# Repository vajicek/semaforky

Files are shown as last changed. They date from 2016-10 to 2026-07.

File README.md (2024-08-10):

# semaforky
Android/Arduino-based DIY system for remote-controlled signaling for sport events

**NEW!: The next-gen version is based on a web app hosted by the device on its own Wi-Fi network. See [web_app](web_app).**

Semaforky is a client-server software for Android/web browsers and several Arduino-based controllers (clients) of various signaling devices:
- Semaphore lights (red, yellow, green)
- Segment clock display
- Siren/acoustic device

This platform was originally designed for archery competitions according to World Archery rules (see [rules](https://www.worldarchery.sport/rulebook/search/clock)). The solution is intended to replace an outdated cable-based predecessor.

## Original motivation

Server app             |  Client hardware
:-:|:-:
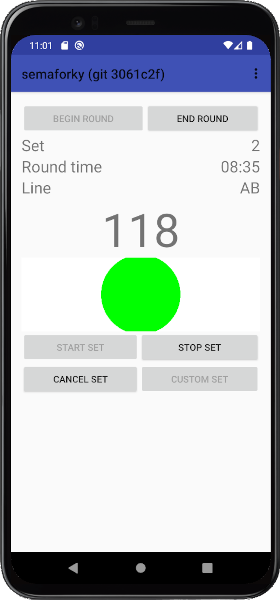
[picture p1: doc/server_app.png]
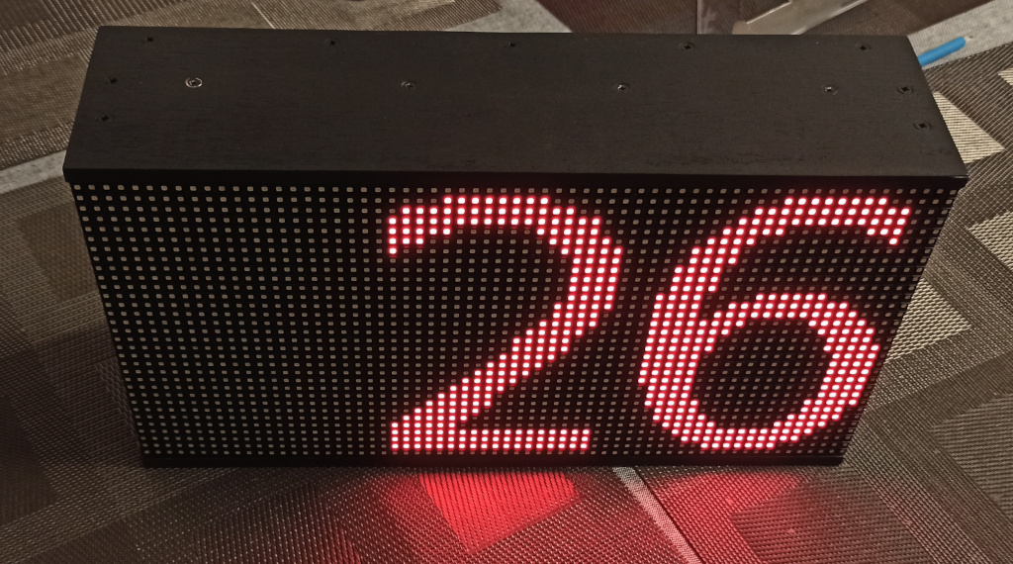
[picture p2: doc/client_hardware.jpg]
  |  

## Original goals
- Most of the existing devices should be preserved, with the addition of a remote transmitter and power source.
- Simple construction blueprints for hardware should also be provided (TBD).
- A simple [application](android_app) for Android, compatible with most existing devices, should be created to replace the Windows-based custom software.

## Second generation goals
- Provide new, original hardware that is battery-powered (via off-the-shelf power banks), mobile, and simple.
- See [blueprints](hardware).

## Third generation goals
- Replace the Android app with a device-hosted [web app](web_app) that runs on anything with a web browser (laptop, Android device, iPhone).

## Additional features
- Training mode: Various countdown and signaling scenarios (e.g., mini-games) for training coordination and timing for improved form in sports activities.

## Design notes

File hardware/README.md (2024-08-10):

# Hardware for semaforky

It provides plans for:
* PCBs
* Enclosures

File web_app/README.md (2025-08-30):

# semaforky webui
Android/Arduino-based hardware controlled via SPA (single page application) web app from any web browser (smartphone, tablet, laptop, PC, Mac, Windows, Linux, ...).

## Motivation

Any Web Browser          |  Hardware running REST/WEB server
:-:|:-:
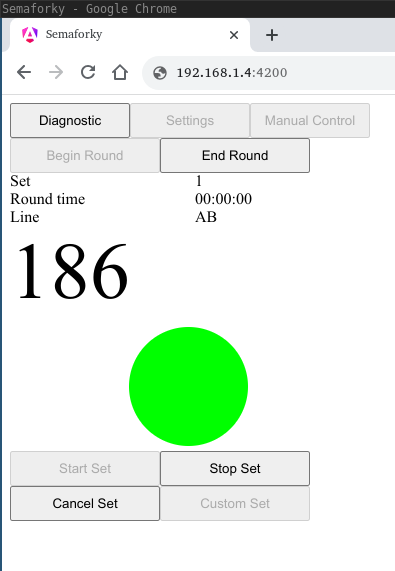
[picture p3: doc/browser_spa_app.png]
  |  

## Documentation

[User Guide](UserGuide_cz.md) (in czech)

## Live demo

See [Live demo](http://vajicek.github.io/semaforky).

## Prerequisites

* Arduino 1.8.19
* ESP 8266 board support for Arduino >=1.6.x, set "http://arduino.esp8266.com/stable/package_esp8266com_index.json" in File > Preferences > Additional Board Manger URLs
* [Support for SPIFFS](https://www.instructables.com/Using-ESP8266-SPIFFS/), [plugin v0.5](https://github.com/esp8266/arduino-esp8266fs-plugin/releases/download/0.5.0/ESP8266FS-0.5.0.zip)
* Arduino Libraries (Tools > Manage Libraries...)
    * [ESPAsyncTCP](https://github.com/me-no-dev/ESPAsyncTCP)
    * [ESPAsyncWebServer](https://github.com/me-no-dev/ESPAsyncWebServer)
    * [ArduinoJson](https://github.com/bblanchon/ArduinoJson)
    * DMD2
    * Adafruit GFX Library
    * Fork of [PxMatrix](https://github.com/vajicek/PxMatrix.git) (new scan pattern added)

## Use devcontainer

Build dev container.
```bash
make build_devcontainer
```

Run dev container.
```bash
make devcontainer
```

### Web application
Build **web app**.
```bash
make setup_ng && make build_webapp
```

### Device application
Install dependencies for **device application**.
```bash
make install_deps
```

Build and install **device application**, e.g. for p5 device (connected to /dev/ttyUSB0).
```bash
make install_p5
```

Rebuild filesystem for **web app** server and flash it to a device (connected to /dev/ttyUSB0).
```bash
rm -f filesystem.bin && make flash-fs
```

## Semaforky application state diagram



## List of features

* The device will connect to the ESSID 'semaforky' if it exists, or create it if not. This provides flexibility to choose which device acts as the hotspot, or to use a separate router.
* Operations divided into rounds (e.g. training + two halves, FITA 900 - 60m/50m/40m) and rounds into sets (e.g. 10 or 12 sets).
* Scan - gather all devices on given network (specified by Network option). Display number of clients and capabilities (semaphore, siren, line indicator, clock) provided.
* Configurable number of lines - 1 or 2
* Configurable lines rotations - SIMPLE (round 1: AB CD, AB CD, ..; round 2: CD AB, CD AB, ..), ALTERNATING (AB CD, CD, AB, AB, ..)
* Configurable set time, waiting time and warning time.
* Delayed start - set time of start and it will automatically start the first set while showing countdown to start.
* Configurable brightness of all devices.
* Optional sound coming from application. Usable in combination with bluetooth speaker.
* Store configuration in cookies.
* Store state in cookies - should survive page refresh.
* Set cancel (It is like set stop but without incrementing set counter).
* Set pause and resume.
* Manual control for testing purposes (audio, semaphore, clock).

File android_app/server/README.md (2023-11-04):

# Android APP to control Semaforky clients

## Build from command-line

### Clean
```bash
./gradlew clean
```

### Build release apk
```bash
./gradlew assembleRelease
```

### Build debug apk
```bash
./gradlew assembleDebug
./gradlew installDebug
```

### Install to Android device
```bash
adb install app/build/outputs/apk/release/app-release.apk
```

### Uninstall semaforky from Android device
```bash
adb shell pm uninstall -k com.vajsoft.semaforky
```

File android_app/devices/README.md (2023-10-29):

# Clients based on Wemos D1 mini (ESP8266)

## Prerequisites
* Install [Arduino IDE](https://www.arduino.cc/en/software)

* Install support for ESP8266 [http://arduino.esp8266.com/stable/package_esp8266com_index.json](http://arduino.esp8266.com/stable/package_esp8266com_index.json)

* Install semaforky_common as local library

	* On Windows
	```cmd
	cd Arduino\libraries
	mklink /D semaforky_common semaforky_github\client\semaforky_common
	```
	* On Linux
	```bash
	cd Arduino\libraries
	ln -s semaforky_github/client/semaforky_common
	```
	* Restart Arduino Studio

## Upload sketch in ArduinoIDE
* Open one of sketches, i.e. **\*_client/\*.ino**
* Connect ESP8266 with USB
* Upload program

## Upload sketch from command-line
* Install [Arduino-CLI](https://arduino.github.io/arduino-cli/)
* Install **\*.ino** from command-line
```bash
arduino-cli compile --fqbn esp8266:esp8266:d1 <*_client>
arduino-cli upload -p /dev/ttyUSB0 --fqbn esp8266:esp8266:d1 <*_client>
```

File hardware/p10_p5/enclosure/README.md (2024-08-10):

# Simple plywood enclosure

* Version 1
* Sliding back
* Material
  * 6.5mm plywood
    * 2 x 86mm x 320mm
    * 1 x 160mm x 320mm
  * 44mm x 24mm timber
    * 2 x 160mm
  * 18mm x 18mm timber
    * 2 x 320mm
    * 1 x 272mm
    * 2 x 124mm
* Glue wooden parts together or use 3mm x 20mm flat head wood screws.
* Panel is mounted with 4mm x 40mm metric screws through 44mm x 24mm pillars (they must be sank into the wood ~10mm).

## Plan
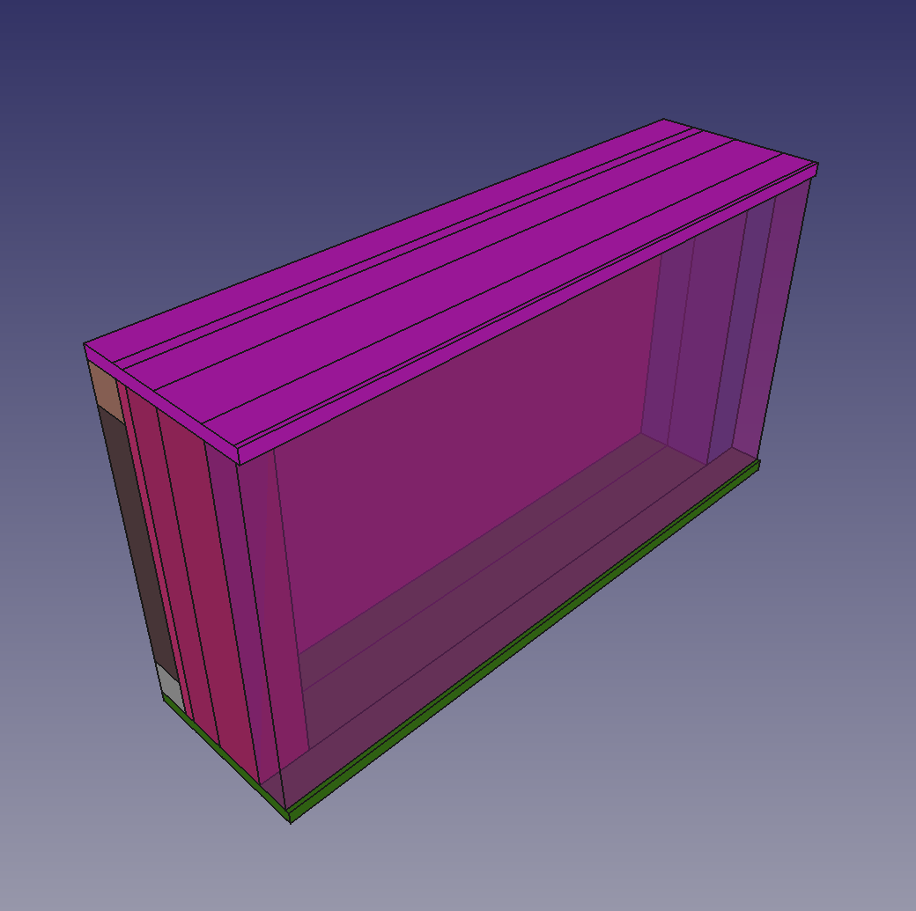
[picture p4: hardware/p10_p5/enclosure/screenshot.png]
Plan


## Components
Components

## The result
Enclosure

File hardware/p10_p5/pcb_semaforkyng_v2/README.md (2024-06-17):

# Custom PCB design in gerber files

* Version 2
  * Voltage protection
  * Pulse generator to keep powerbank running (inspired by  [How to stop a power bank from turning off](https://technoreview85.com/how-to-stop-a-power-bank-from-turning-off/))
* Examine with gerbb utility.
* Edit using [EasyEDA](https://easyeda.com/) online editor.
* Order with [PCBWay](https://www.pcbway.com/) service.

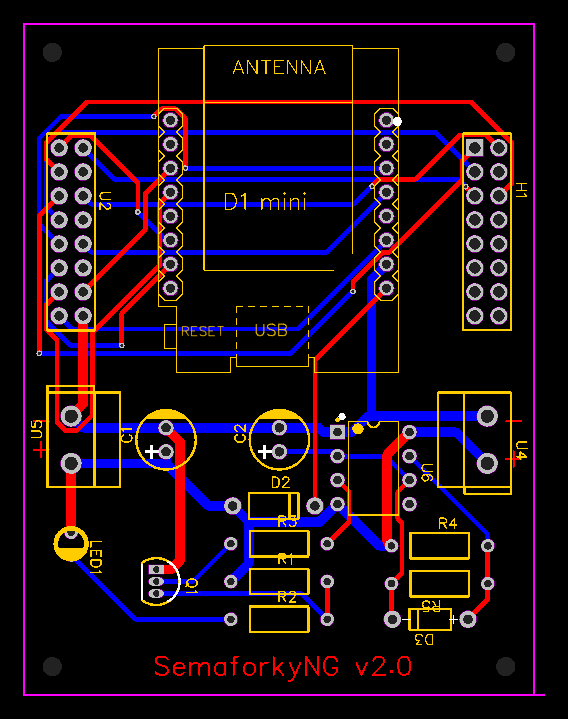
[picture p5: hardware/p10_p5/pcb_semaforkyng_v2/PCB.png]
PCB overview


## List of components

|mark |component |link|
|---|---|----|
|U5, U4 |KF301-5.0-2P |[link](https://www.aliexpress.com/item/4000290521933.html)|
|U2, H1 |2.54 Pin Header Connector||
|C1 |220 uF ||
|Q1 |2N2222 ||
|LED1 | ||
|C2 |10 uF ||
|D2 |1N5817-T ||
|R3 |1k Ohm ||
|R1 |33 Ohm ||
|R2 |220 Ohm ||
|U6 |IC 555 ||
|R4 |270k Ohm ||
|R5 |1M Ohm ||
|U1 |WeMos D1 Mini Pro V3.0 |[link](https://www.aliexpress.com/item/1005004344044423.html)|

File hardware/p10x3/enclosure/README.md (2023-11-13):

# Simple plywood enclosure

* Version 1
* Sliding back
* Material
  * 6.5mm plywood
    * 2 x 493mm x 85mm
    * 2 x 320mm x 60mm
    * 3 x 320mm x 164.33mm
  * 44mm x 24mm timber
    * 2 x 480mm
  * 18mm x 18mm timber
    * 2 x 493mm
    * 4 x 284mm
* Glue wooden parts together or use 3mm x 20mm flat head wood screws.
* Panel is mounted with 4mm x 40mm metric screws through 44mm x 24mm pillars (they must be sank into the wood ~10mm).

## Plan
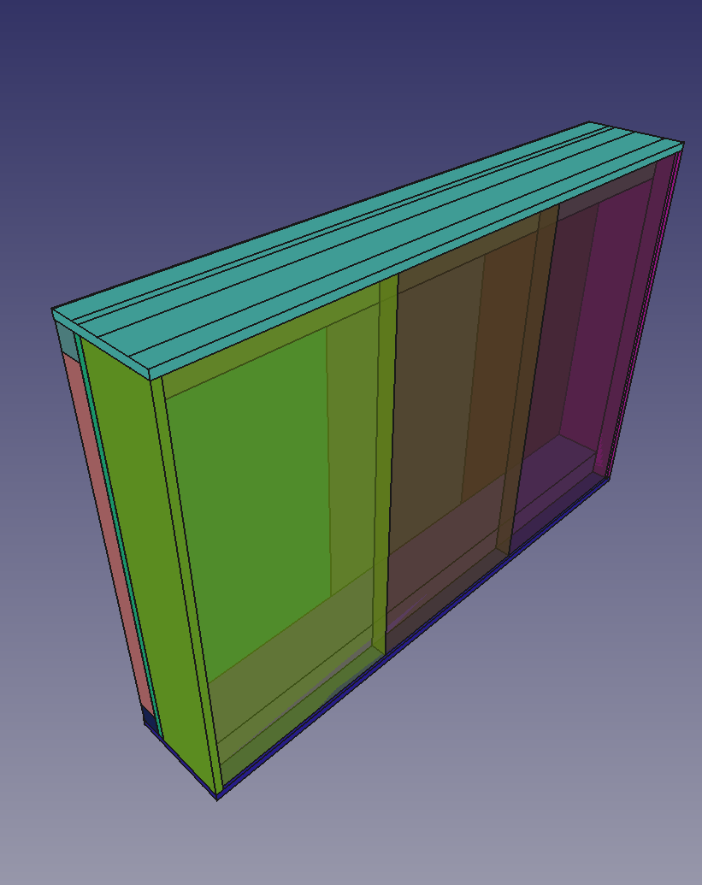
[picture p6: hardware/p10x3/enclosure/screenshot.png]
Plan


## Components
Components

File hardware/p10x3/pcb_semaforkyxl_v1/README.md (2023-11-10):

# Custom PCB design in gerber files

* Version 1
  * Voltage protection
  * Pulse generator to keep powerbank running (inspired by  [How to stop a power bank from turning off](https://technoreview85.com/how-to-stop-a-power-bank-from-turning-off/))
* Examine with gerbb utility.
* Edit using [EasyEDA](https://easyeda.com/) online editor.
* Order with [PCBWay](https://www.pcbway.com/) service.

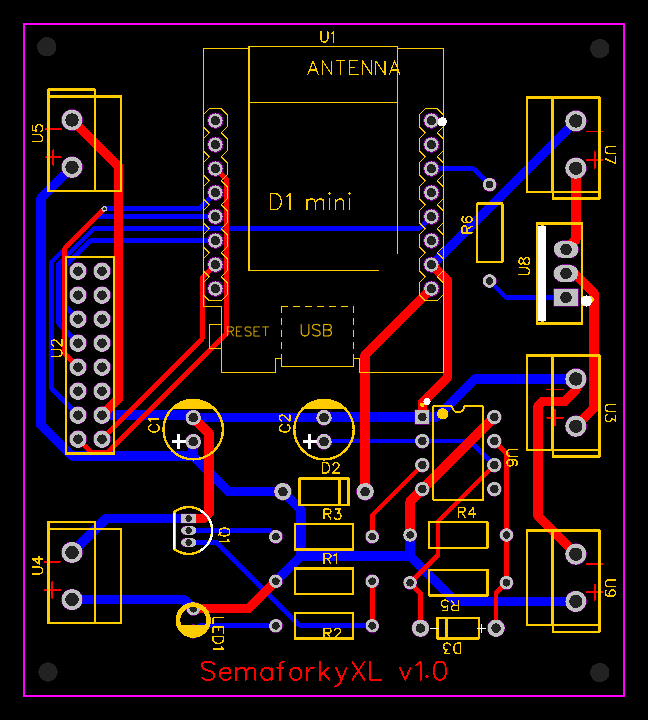
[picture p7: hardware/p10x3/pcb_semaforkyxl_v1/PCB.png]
PCB overview


## List of components

|mark |component |link|
|---|---|----|
|U5,U4,U7,U3,U9|KF301-5.0-2P |[link](https://www.aliexpress.com/item/4000290521933.html)|
|U2 |2.54 Pin Header Connector||
|C1 |220 uF ||
|Q1 |2N2222 ||
|LED1 | ||
|C2 |10 uF ||
|D2 |1N5817-T ||
|R3 |1k Ohm ||
|R1 |33 Ohm ||
|R2 |220 Ohm ||
|U6 |IC 555 ||
|R4 |270k Ohm ||
|R5 |1M Ohm ||
|R6 |100 Ohm ||
|U8 |TIP 120 ||
|U1 |WeMos D1 Mini Pro V3.0 |[link](https://www.aliexpress.com/item/1005004344044423.html)|

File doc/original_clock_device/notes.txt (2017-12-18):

SAA 1064
GS9526 / GD75189A - quadruple line receiver
SN7406N - hex inverter
BD 675 - NPN Darlington Bipolar Power Transistor
BS-A606RD - LED display

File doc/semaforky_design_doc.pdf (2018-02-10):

1 Architecture overview

2 Main App
2.1 GUI
2.2 Settings
2.3 Backend

3 Device Clients

# Semaforky Design doc

# 1 Architecture overview

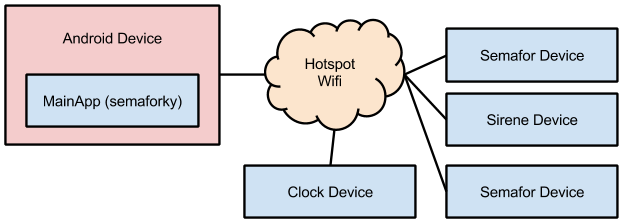
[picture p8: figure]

# 2 Main App

## 2.1 GUI

MainActivity
Begin, End - Set and reset counters, starts round timer, resets time Set - set number in round
Round time - time since begin
Set counter
Semaphore
Line - line number
Start set - add set +1, start counting, starts set timer, scheduler
Stop set - stop counting, end signal
Cancel set - decrease set number -1, reset counter. Only once? Only if started?

SettingsActivity
OK - reloads main activity (language change) TODO: save settings...
Cancel - close, return to old

## 2.2 Settings

Language
Lines
Set Time
Preparation
Warning time
Sets per round
Continuous mode

## 2.3 Backend

Scheduler
Single object (singleton?) inside of main activity Round timer - NO, separate
Set timer

List of planned events
Event - run(), compare(), initialized with all resources

Called from mainActivity

Schecheduler public interfaces
startSet
events.add(new SemaphoreEvent events.add(new ClockEvent
events.add(new SemaphoreEvent

stopSet
cancelSet
startRound -TODO: remove
EndRound -TODO: remove

Controller
run() - read
SoundManager

Init - initialize loading of all samples from raw resources.. HotspotManager
Enable and set hodspot
MainController
TODO: rename?
Implement state machine
- List of states
- Started
- Round started
- Set Started
■ Ready
■ Fire
■ Warning
- Set Stopped
- Round stopped

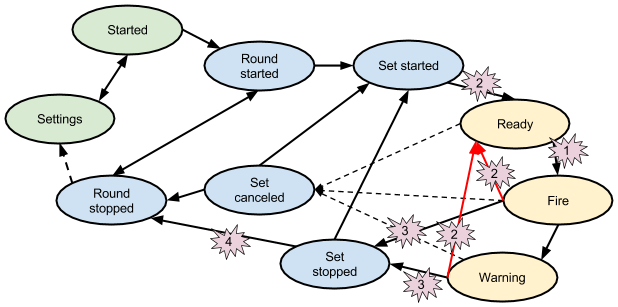
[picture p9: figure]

Server for other clients/controllers SireneController
ClockController
SemaphoreController

# 3 Device Clients

## Semafor device client

TODO(vajicek): Hardware design block diagram

## Clock device client

TODO(vajicek): Hardware design block diagram

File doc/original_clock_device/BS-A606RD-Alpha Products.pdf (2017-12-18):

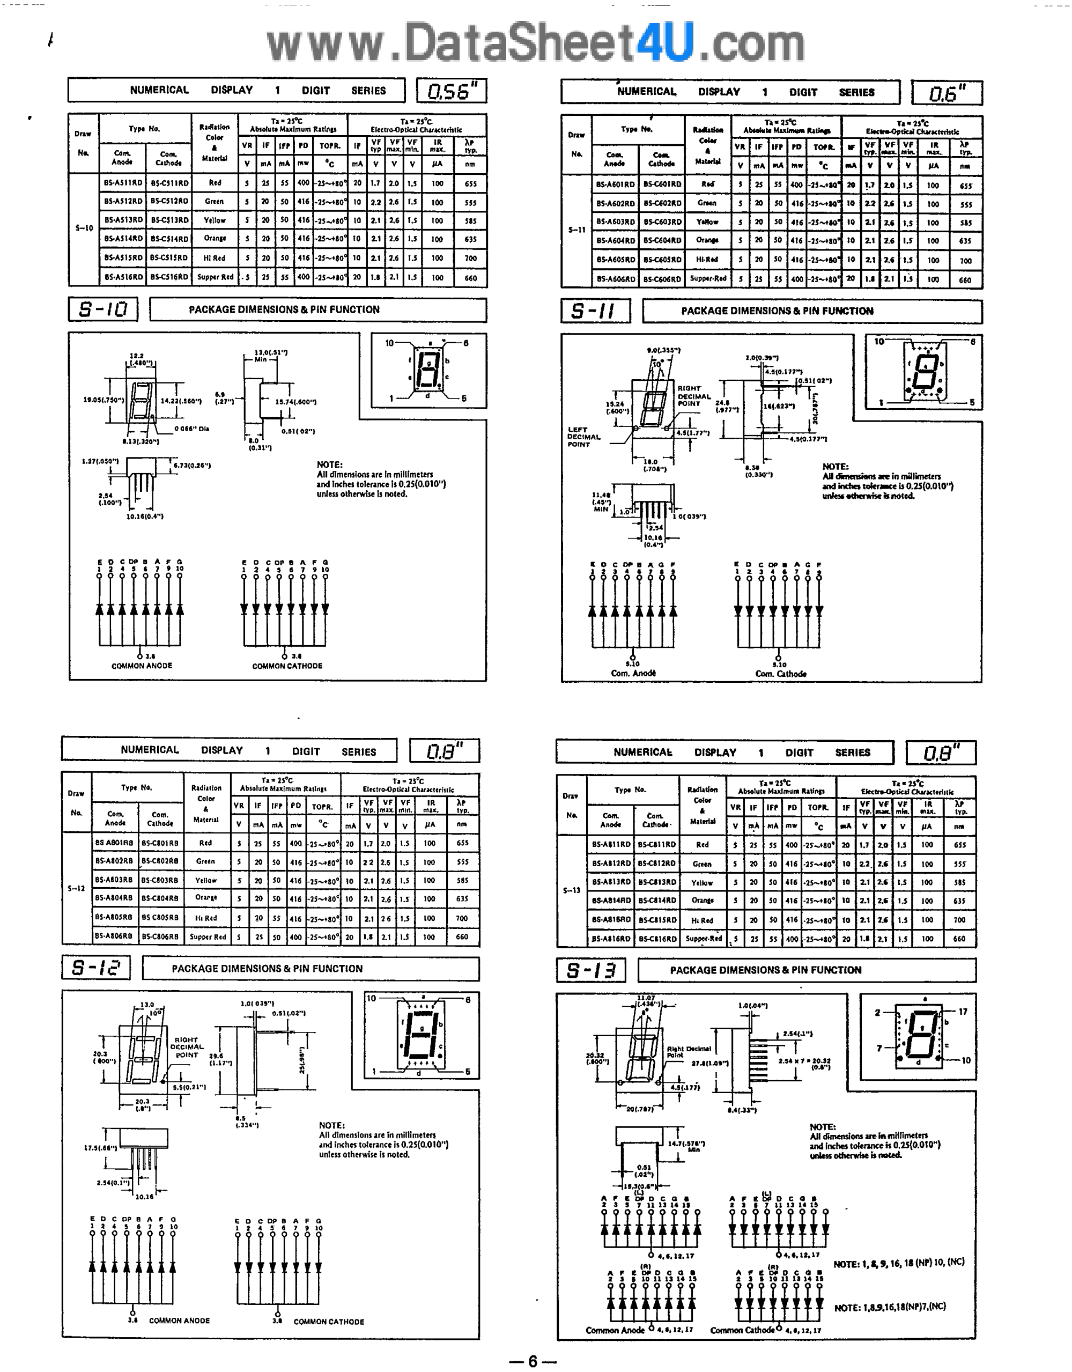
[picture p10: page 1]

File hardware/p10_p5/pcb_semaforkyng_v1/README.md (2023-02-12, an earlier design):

# Custom PCB design in gerber files

* Examine with gerbb utility.
* Edit using [EasyEDA](https://easyeda.com/) online editor (Import *.EasyEDA.json files).
* Order with [PCBWay](https://www.pcbway.com/) service (Zip before upload 'zip PCB.zip *').

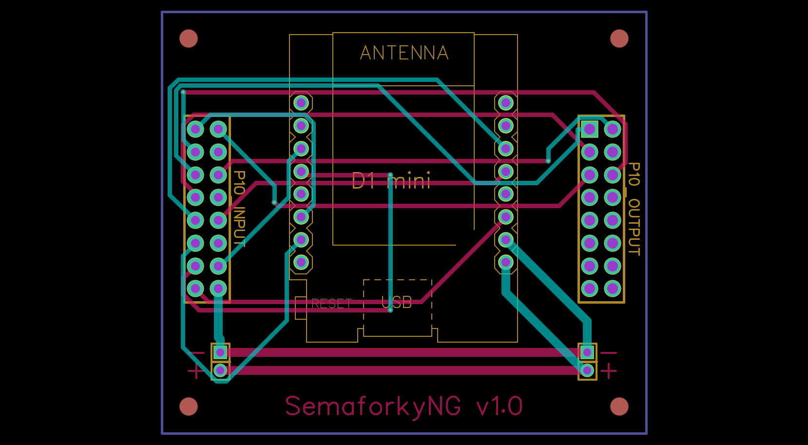
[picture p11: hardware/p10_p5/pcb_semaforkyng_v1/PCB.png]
PCB overview


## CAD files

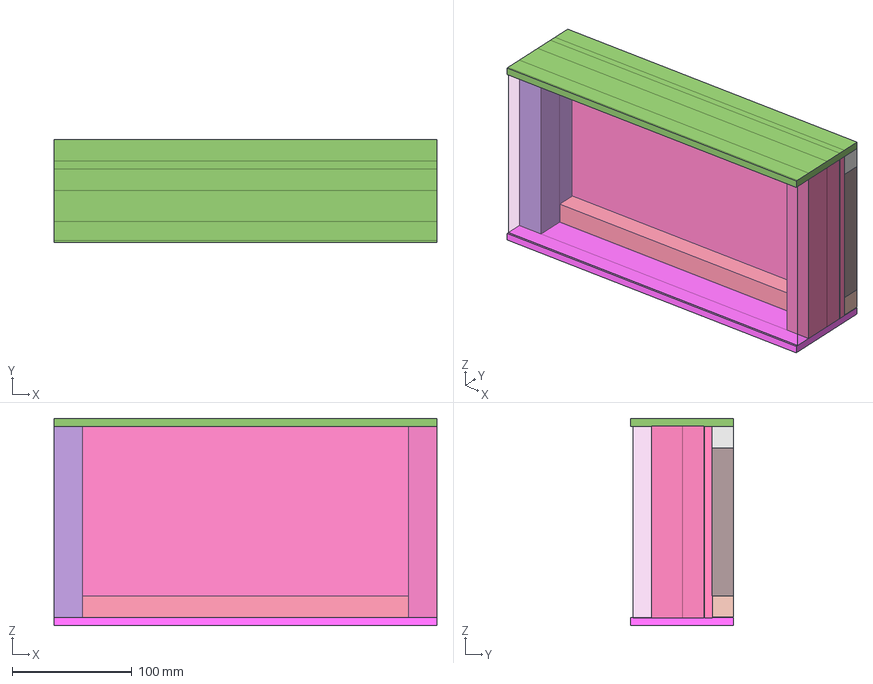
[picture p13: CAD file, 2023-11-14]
hardware/p10_p5/enclosure/enclosure.FCStd
320.0 x 86.0 x 173.0 mm
Top
Bottom
RightPillar
LeftPillar
BottomEdge
TopEdge
TopInternalEdge
Back
HandleRight
HandleLeft
P5Panel

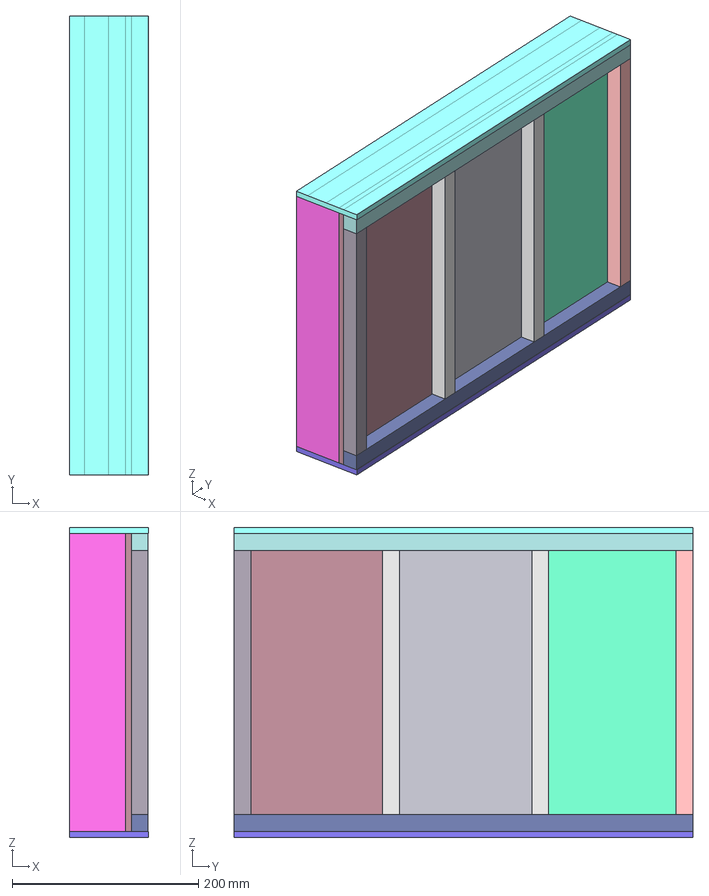
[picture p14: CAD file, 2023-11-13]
hardware/p10x3/enclosure/enclosure.FCStd
85.0 x 493.0 x 333.0 mm
p10panel_1
p10panel_2
p10panel_3
bottomEdge
topEdge
bottom
rightSide
leftSide
top
back_1
back_2
back_3
bottomBackEdge
topBackEdge
rightBackEdge
leftBackEdge
rightMiddleBackEdge
leftMiddleBackEdge

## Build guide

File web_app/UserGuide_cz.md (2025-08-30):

# Semaforky - Uživatelská příručka

## Napájení
Zařízení je možné napájet přes USB konektor. V závislosti na verzi může být použita USB-A zástrčka, USB-C zásuvka nebo microUSB zásuvka. Jako zdroj napájení je možné využít powerbanku nebo síťový napájecí adaptér.

V závislosti na konfiguraci může být powerbanka součástí zařízení, a externí USB konektor pak slouží pouze k jejímu nabíjení.

## Uvedení do provozu
Po připojení napájení se zařízení zapíná kolébkovým vypínačem. Pokud je zařízení zapnuté a napájené, kontrolka vypínače svítí.

## Nastavení Wi-Fi
Zařízení vyžaduje k provozu Wi-Fi síť: SSID=semaforky, heslo=semaforky.
1) Pokud síť při spuštění zařízení neexistuje, zařízení se přepne do režimu hotspotu a vytvoří síť se stejným SSID a heslem.
2) Pokud síť existuje (např. ji poskytuje smartphone nebo Wi-Fi router), zařízení se pokusí k ní připojit pomocí WPA2 a zadaného hesla.

V obou případech je možné se na tuto síť připojit jiným zařízením (**ovladačem**), které umožňuje ovládání prostřednictvím webového prohlížeče (smartphone, tablet, notebook apod.).

V případě 1) je webové rozhraní dostupné na adrese (ve webovém prohlížeči) [192.168.4.1](). V případě 2) závisí adresa na typu a nastavení zařízení, které hostuje Wi-Fi síť.

Doporučení pro ovládání ze smartphonu: nastavte si telefon tak, aby neusínal, nevypínal displej a neodpojoval se od Wi-Fi při delší nečinnosti.

## Ovládání
1) Jděte do **Webového Rozhraní** (např. [192.168.4.1]()), otevře se vám **Hlavní Obrazovka**
2) Pokud se nenacházíte na síti **192.168.4.1**, jděte na **Obrazovku Nastavení** (tlačítko "Nastavení"/"Settings") a změňte **Síť** ("Síť"/"Network") z 192.168.4.0 na jinou síť (nastavení hotspotu z Wifi možnosti 2), viz výše). A vraťte se do Hlavní Obrazovky (tlačítko "OK").
3) Klikněte na tlačítko "Skenuj"/"Scan". Rozhraní vyhledá všechna dostupná zařízení na síti. Jedno nebo více, pokud jich chcete provozovat najednou víc i více typů (semaforky, siréna, hodiny). Počkejte dokud tlačítko "Skenuj"/"Scan" opět nezmění stav na aktivní.
4) Nyní můžete vyzkoušet funkce v **Obrazovce Manuálního Ovládání** (tlačítko "Manuální ovládání"/"Manual control"). Poté se vraťte na hlavní obrazovku.
5) Nastavte si vlastnosti časomíry na Obrazovce Nastavení:
	* "Jazyk" - Jazyk rozhraní.
	* "Řady" - Počet střeleckých řad, 1 nebo 2.
	* "Rotace řad" - Která řada začíná sadu AB/CD. Pokud jsou nastavené 2 řady.
		* "Po kolech" - Celé první kolo začíná sadu řada AB, celé druhé kolo začíná řada CD.
		* "Po sadách" - První sadu začíná AB, druhou sadu začíná CD, třetí AB, atd.
		* "Bez rotace" - Každou sadu začíná AB.
	* "Čas sady" - kolik je času (v sekundách) na vystřelení všech šípů, např 120 na tři šípy, 240 na šest šípů.
	* "Přípravný čas" - doba (v sekundách) pro nástup na čáru.
	* "Varovný čas" - kolik sekund před koncem sady se má semafor přepnout do žluté barvy.
	* "Jas" - Jas hodin. Má vliv na dobu provozu na baterii. Je možné přizpůsobit světelným podmínkám a vzdálenosti umístění.
	* "Zvuk" - zda má **ovladač** přehrávat zvukové znamení (prostředky webového prohlížeče). Vhodné v případě, že nemáte dedikovanou sirénu.
	* "Síť" - síť (adresa /24 sítě končí .0, na rozdíl od adresy zařízení) na které se mají hledat připojená zařízení.
	* Tlačítko
		* "OK" aplikuje změny a naviguje na hlavní obrazovku.
		* "Zrušit" zapomene provedené změny a naviguje na hlavní obrazovku.
6) "Začátek kola" - otevře **Dialog pro Začátek Kola** s možnostmi ovlivnit způsob začátku a průběhu kola:
	* "Teď" - Začne první sadu kola podle nastavení (viz výše).
	* "Odložený" - Začne první sadu kola v daný čas lokálního času. Na hodinách poběží odpočet do začátku.
	* "Nepřetržitý" - Postupně spustí daný počet kol o daném počtu sad podle nastavení (viz výše). Pro účely testování, stability a výdrže baterie.
	* "Zrušit" - zavře dialog.
7) V průběhu kola a sady, uživatelské rozhraní aktivuje a deaktivuje **Ovládací Tlačítka** podle toho, co je možné udělat ("Start..", "Pauza", "Pokračovat", ..):
	* "Konec sady" - Ukončení sady před uplynutím nastaveného času.
	* "Začátek sady" - Začátek druhé, třetí a každé další sady v daném kole.
	* "Konec kola" - Pro ukončení kola, resp. ukončení poslední sady v ukončovaném kole před koncem nastaveného času na sadu.
	* "Variabilní sada" - Otevře **Dialog pro Variabilní Sadu**, který umožňuje nastavení délky sady pro případy dostřelů.
	* "Zrušit sadu" - Ukončení sady, pokud dojde v výjimečné situaci před začátkem střelby. Nedojde k rotaci řad jako v případě normálního (předčasného) ukončení sady.
	* "Pauza"/"Pokračovat" - Zastavení a pokračování v odpočtu, pro účely řešení výjimečných situací.
8) **Informační Panel** ukazuje počty a typy ovládaných zařízení. Některá zařízení naplňují více funkcí (jeden klient může fungovat jako semafor a hodiny zároveň):
	* Klienti - celkový počet hardwarových zařízení.
	* Semaforky - počet zařízení ukazující trojici semaforových barev.
	* Řady - počet zařízení ukazující, která řada střílí.
	* Hodiny - počet zařízení, která ukazují zbývající čas.
	* Sirény - počet zařízení, která zajišťují zvukovou signalizaci.
	* Odpočet - počet zařízení, která provádí autonomní odpočet (alternativa k Hodiny).

## Řešení problémů

#### Hodiny nereagují, nebo se zpožďují.
* Všechno vypněte a začněte znovu.
* Ujistěte se že vzdálenosti od **ovladače** nejsou moc velké (20+ metrů).
* Ujistěte se, že se **ovladač** neodpojil od WiFi sítě.

#### Skenování nenalezne všechna zařízení (klienty).
* Ujistěte se, že zařízení jsou zapnuta a jejich napájení je v pořádku.
* Vypněte a zapněte chybějící zařízení, pár sekund počkejte a zkuste sken znovu.

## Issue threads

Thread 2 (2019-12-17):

Andorid >=8.0 problem with programmatic Wifi Hotspot

vajicek, 2019-12-17:
The solution is partially based on programmatic setup of Wifi Hotspot so that signaling devices can connect to the device. Hotspot can still be created manually.

Two ways to fix:
1) Find solution how to do it... in >=8.0
2) Find different way to establish connection between Android device (wifi) and ESP8266

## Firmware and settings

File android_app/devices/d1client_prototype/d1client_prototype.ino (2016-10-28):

/// Copyright (C) 2016, Vajsoft
/// Author: Vaclav Krajicek <vajicek@volny.cz>

#include <ESP8266WiFi.h>
#include <SPI.h>

// connection properties
const char* ssid = "semaforky";
const char* password = "semaforky";
const char servername[] = "192.168.43.1";
const int port = 8888;

const int SEMAPHORE_CLIENT = 1;
const int CLOCK_CLIENT = 2;

bool wifi_disabled = false;

/// data chunk
struct ControlChunk {
  int light;
  int status;
  ControlChunk() : light(0), status(0) {   
  }
};

struct RegisterChunk {
  int type;
};

/// Process object, state machine behavior
struct Process {
	WiFiClient client;
	String result;
  bool is_connected;
  ControlChunk last_chunk;

  /// connect to server specified by global variables
  void Connect();

  /// OnConnect event
  virtual void OnConnect();

  /// disconnect
  void Disconnect();

  /// non blocking processing of states
  void Execute();

  /// init output pins
  virtual void Init();

  /// read data chunk
  void ReadControlChunk();

  /// set outputs
  virtual void SetLights();

  Process();
};

Process::Process() : 
  is_connected(false) {
}

void Process::ReadControlChunk() {
  Serial.println("ReadControlChunk");
  client.read((uint8_t*)(&last_chunk), sizeof(last_chunk));
  Serial.print("last_chunk.light=");
  Serial.println(last_chunk.light);
  Serial.print("last_chunk.status=");
  Serial.println(last_chunk.status);
}

void Process::OnConnect() {
}

void Process::Connect() {
  if (client.connect(servername, port)) {  //starts client connection, checks for connection
    Serial.println("connected");
    is_connected = true;
    OnConnect();
  } else {
    Serial.println("connection failed"); //error message if no client connect
    Serial.println();
    is_connected = false;
  }
}

void Process::Disconnect() {
  client.stop(); //stop client
  is_connected = false;
}

void Process::SetLights() {
}
  
void Process::Execute() {
  if (!is_connected && !wifi_disabled) {
    Connect();
  } else  {
    if (client.connected()) {
      if (client.available()) {
        ReadControlChunk();
      }
    } else {
      Serial.println("disconnected");
      is_connected = false;
    }
  }
  SetLights();
}

void Process::Init() {
}

/// Semaphore client specialization.
struct SemaphoreProcess : public Process {
  virtual void Init();
  virtual void SetLights();
  virtual void OnConnect();
};

void SemaphoreProcess::OnConnect() {
  RegisterChunk chunk{1};
  client.write((uint8_t*)(&chunk), sizeof(RegisterChunk));
}

void SemaphoreProcess::SetLights() {
  digitalWrite(14, last_chunk.status == 1 ? HIGH : LOW);
  digitalWrite(12, last_chunk.status == 2 ? HIGH : LOW);
  digitalWrite(13, last_chunk.status == 3 ? HIGH : LOW);
}

void SemaphoreProcess::Init() {
  pinMode(14, OUTPUT);
  pinMode(12, OUTPUT);
  pinMode(13, OUTPUT);
}

/// Clock client specialization.
struct ClockProcess : public Process {
  const static int digit_count = 4;
  const static int segment_count = 7;
  int segment_pin[7] = {2,4,5,12,13,14,15};
  int digit_pin[digit_count] = {3, 1, 16, 0};
  bool digit_configuration[11][7] = {
    {true, true, true, true, true, true, false},      //0
    {false, true, true, false, false, false, false},  //1
    {true, true, false, true, true, false, true},
    {true, true, true, true, false, false, true},     //3
    {false, true, true, false, false, true, true},    //4
    {true, false, true, true, false, true, true},
    {true, false, true, true, true, true, true},      //6
    {true, true, true, false, false, false, false},   //7
    {true, true, true, true, true, true, true},       //8
    {true, true, true, true, false, true, true},      //9
    {false, false, false, false, false, false, false} //off
  };
  virtual void Init();
  virtual void SetLights();
  virtual void OnConnect();
};

void ClockProcess::OnConnect() {
  RegisterChunk chunk{2};
  client.write((uint8_t*)(&chunk), sizeof(RegisterChunk));
}

void ComputeDigits(int* digits, int digit_count, int value) {
  int divider = 1;
  for (int i = 0; i < digit_count; i++) {
    digits[digit_count - i - 1] = (value / divider) % 10;
    divider *= 10;
  }
}

void ClockProcess::SetLights() {
  int digits[4];
  ComputeDigits(digits, digit_count, last_chunk.status);
  for (int i = 0; i < digit_count; i++) {
    digitalWrite(digit_pin[i], LOW);
    for (int j = 0; j < segment_count; j++) {
       digitalWrite(segment_pin[j], digit_configuration[digits[i]][j] ? HIGH : LOW);
    }
    delay(4);
    digitalWrite(digit_pin[i], HIGH);
  }  
}

void ClockProcess::Init() {
  for (int i = 0; i < segment_count; i++) {
    pinMode(segment_pin[i], OUTPUT);
  }
  for (int i = 0; i < digit_count; i++) {
    pinMode(digit_pin[i], OUTPUT);
  }
}

void PrintWiFiInfo() {
  Serial.println("Connected!");
  Serial.print("localIP: ");
  Serial.println(WiFi.localIP().toString());
  Serial.print("gatewayIP: ");
  Serial.println(WiFi.gatewayIP().toString());
  Serial.print("macAddress: ");
  Serial.println(WiFi.macAddress());
}

void ConnectWiFiAP() {
  Serial.print("Connecting to ");
  Serial.println(ssid);
  WiFi.begin(ssid, password);
  while (WiFi.status() != WL_CONNECTED) {
    delay(50);
    Serial.print(".");
  }
  Serial.println("");
}

/// global instance
//Process global;
SemaphoreProcess global;
//ClockProcess global;

void setup() {
  Serial.begin(115200);

  global.Init();

  if (!wifi_disabled) {
    ConnectWiFiAP();
    PrintWiFiInfo();
  }
}

void loop() {
  //delay(500);
  global.Execute();
}

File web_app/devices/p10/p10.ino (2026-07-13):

/// Copyright (C) 2023, Vajsoft
/// Author: Vaclav Krajicek <vajicek@volny.cz>

#include "semaforky_webui_common_esp8266.h"

BaseSettings baseSettings {
	true, // serve spa
	false, // force_hotspot
	"p10-01", // dns
	"semaforky", // ssid
	"semaforky", // password
	"clock,semaphore" }; // capabilities
P10 client(&baseSettings);

void setup(void) { client.Init(); }

void loop(void) { client.Execute(); }

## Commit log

2016-10-22 Implemented android app and arduino clients for semaforek and clock
2017-06-18 Shortened timer period.
2017-07-15 Solved code share for various semaforky client types
    [clock_client.ino, semaforky_common.h, wifi.h]
2017-12-18 Finished clock client prototype
2018-01-27 Added status LEDs
2018-06-24 Experiment with sound thread
2018-07-14 Fixed settings creation and building & publishing process
    [SettingsActivity.java]
2018-11-26 Minor fix for sirene module
    [semaforky_common.h]
2019-08-04 Switched to the latest support lib
2023-02-12 SemaforkyNG PCB added
    [Drill_NPTH_Through.DRL, Drill_PTH_Through.DRL, Drill_PTH_Through_Via.DRL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]
2023-06-26 Added SemaforkyNG PCB v2
    [Drill_NPTH_Through.DRL, Drill_PTH_Through.DRL, Drill_PTH_Through_Via.DRL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]
2023-10-22 Update with XL PCB and client
    [Drill_NPTH_Through.DRL, Drill_PTH_Through.DRL, Drill_PTH_Through_Via.DRL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]
2023-10-28 Fixed MonoMatrixDisplay wifi vs SPI problem
    [semaforky_common.h, wifi.h]
2023-10-28 Added FreeCad plan for enclosure
    [enclosure.FCStd]
2023-10-29 Added enclosure description
    [enclosure.FCStd]
2023-11-03 Added p10x3 enclosure
    [enclosure.FCStd]
2023-11-04 Added plan with components
    [enclosure.FCStd]
2023-11-04 Implemented custom set and delayed start
    [enclosure.FCStd]
2023-11-12 Enclosure components
2023-11-13 Added middle edges
    [enclosure.FCStd]
2023-11-13 Updated plan
    [enclosure.FCStd]
2023-11-20 Prototype of webserver
2024-02-21 Lines and fix flickering a little for p10x3
    [p10x3.ino, semaforky_webui_common.h]
2024-07-16 Fixed lines rotation switch and round timer
2024-08-10 Restructured repo
    [Drill_NPTH_Through.DRL, Drill_PTH_Through.DRL, Drill_PTH_Through_Via.DRL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]
2024-09-15 Deploy current version
2024-11-17 Fixed routing in device code
    [semaforky_webui_common.h]
2024-11-17 Explicit routing in device app is not needed
2024-12-14 Fixed lines at the end of round
    [semaforky_webui_common.h]
2025-07-21 Autoreconnect and connect on missing, force hotspot
    [p10.ino, p10_semaphore.ino, p10x3.ino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]
2026-07-13 Added suppoer for ESP32 and P10x3
2026-10-13 Basic functionality flow
2026-11-11 Add display control value with on-device image and time display (#5)
    * Added ESP32 semaphore and siren support
    * Add ESP32 Makefile targets
    * Fix ESP32 pin configuration
    * Add ESP32 filesystem targets
    * Name REST control IDs with a ControlValue enum.
    Keep capability strings next to the matching firmware control numbers so the client no longer hardcodes 1-5.
    * WIP
    * Demo, MVP for show raster
    * Add device-side time display
    * Improve image display and settings
    * Add display sample images
    * Update Czech user guide
    * Store display images on device and remove checkerboard demo
    ---------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
